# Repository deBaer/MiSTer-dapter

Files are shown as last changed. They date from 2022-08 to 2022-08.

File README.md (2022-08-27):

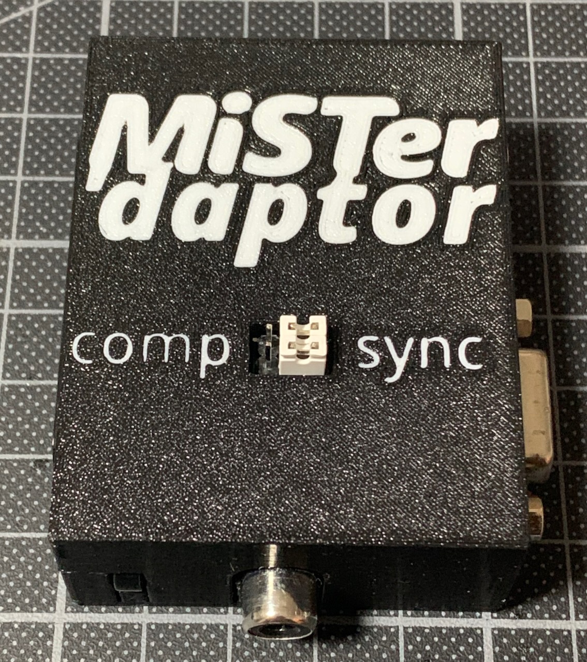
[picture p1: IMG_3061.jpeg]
MiSTer'daptor in case


# MiSTer'dapter
A VGA and audio jack to RGB SCART converter with RCA sync or composite output for the MiSTer FPGA

    Copyright (C) 2022 Simon Kowalewski

    This program is free software; you can redistribute it and/or modify
    it under the terms of the GNU General Public License as published by
    the Free Software Foundation; either version 2 of the License, or
    (at your option) any later version.

    This program is distributed in the hope that it will be useful,
    but WITHOUT ANY WARRANTY; without even the implied warranty of
    MERCHANTABILITY or FITNESS FOR A PARTICULAR PURPOSE.  See the
    GNU General Public License for more details.

    You should have received a copy of the GNU General Public License along
    with this program; if not, write to the Free Software Foundation, Inc.,
    51 Franklin Street, Fifth Floor, Boston, MA 02110-1301 USA.

## Video demonstration
[YouTube](https://youtu.be/DpnR34e562k) (Spoken languague is German, English subtitles are available)
	
## Build yourself
You'll need the [board](board) manufactured on 1.6 mm substrate. Also, you'll need a fitting SCART, VGA, RCA and mini phone jack. (I'll add links later.) You'll also need a 470 ohm resistor for attenuating the sync signal to SCART-safe levels and, optionally but recommended, a capacitor and inductance for the luma trap. I use 33 uH and 68 pF. If you don't use C1 and L1, bridge C1 with a resistor leg.

Optionally, 3D-print the [case](case). If you can multi-color print, print case.stl and print.stl together in different colors. If you cannot, don't print print.stl. If you want to use the case, populate the jumpers on the back side of the PCB (the side without silkscreen print).

## Buy from me
I don't have a web shop right now, so just send a mail to deBaer@gmail.com and tell me how many kits you want (15 €/kit), your preferred jumper color (black, white, blue, red, green and yellow available), if I should solder and test them for you (+10 €/kit), if you want cases (+10 €/case) and your post address (postage is 6€ flat for Germany for registered mail, I'll calculate the International postage on demand). I'll send you a confirmation with the expected delivery date, the final price and payment information, most likely Paypal. If you cannot or don't want to use Paypal, also indicate that in your email. Use a subject header containing "[daptor]" so I'll see the mail.

## Buy from someone else
If you offer to sell MiSTer'dapter kits, I'll list you here. Non-EU sellers are especially welcome, as I don't like customs forms. But please, attribute me and link back to this page.

## Usage
Connect the MiSTer'daptor to your MiSTer with a normal VGA cable.

Note: For the Guncon 2 or any other lightguns to work, the video has to go directly from the core to the CRT. No `vga_scaler`, no `scandoubler`! Also, no plasma, LCD, OLED! It may work with `direct_video` over the HDMI port, but that depends on both the device as well as the settings.

### RGB SCART
Connect the MiSTer'daptor to your TV with a RGB-capable SCART cable (not all are). For audio, connect the MiSTer'daptor with a normal TRS mini jack cable to the MiSTer. Optionally, connect Guncon 2 or other controllers that need sync to the RCA jack. Use these .ini settings:

```
forced_scandoubler=0
ypbpr=0 
composite_sync=1
vga_scaler=0
```

### Composite
Connect the MiSTer'daptor RCA plug to a composite input (normally yellow) on the TV. Connect the MiSTer audio out directly to the TV. You need to use [Y/C-capable cores](https://github.com/MikeS11/MiSTerFPGA_YC_Encoder) and switch to Y/C video mode in the core config dialog. Use these .ini settings:

```
forced_scandoubler=0
ypbpr=0 
composite_sync=1
vga_scaler=0
vga_sog=1
```

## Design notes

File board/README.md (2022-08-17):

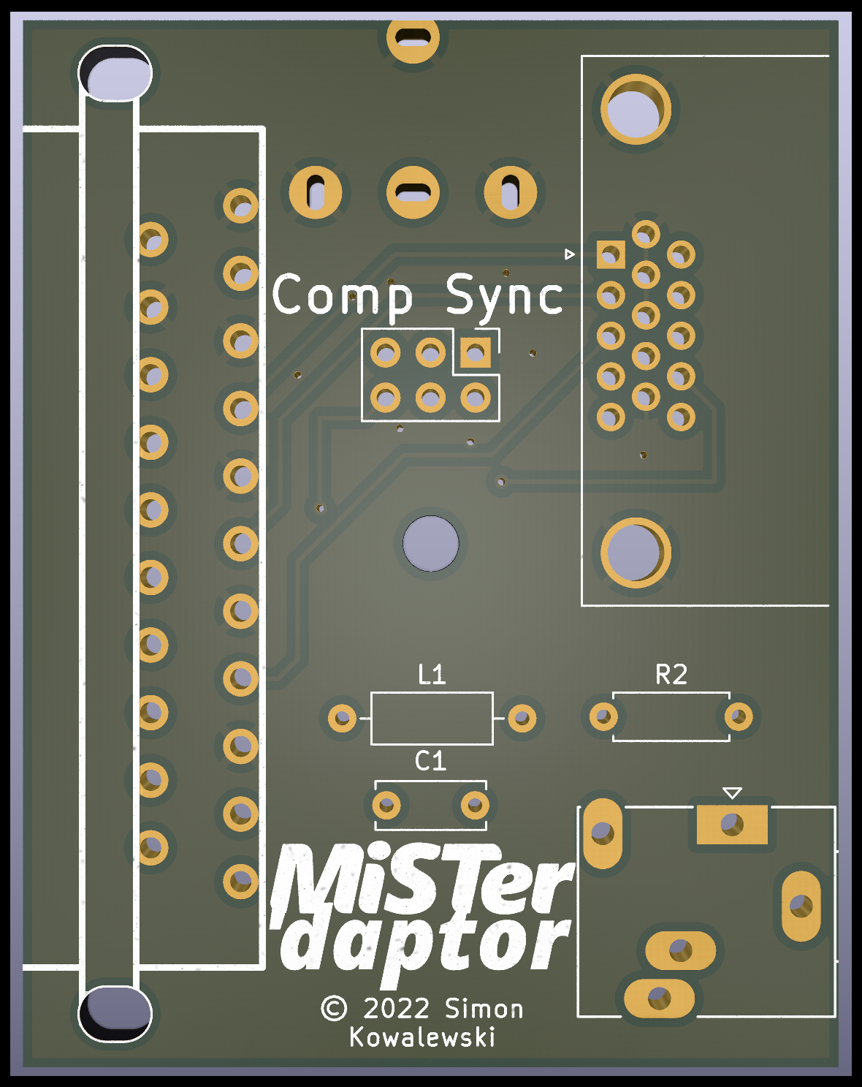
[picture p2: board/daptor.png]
MiSTer'daptor board


# MiSTer'dapter board
A VGA and audio jack to RGB SCART converter with RCA sync or composite output for the MiSTer FPGA

    Copyright (C) 2022 Simon Kowalewski

    This program is free software; you can redistribute it and/or modify
    it under the terms of the GNU General Public License as published by
    the Free Software Foundation; either version 2 of the License, or
    (at your option) any later version.

    This program is distributed in the hope that it will be useful,
    but WITHOUT ANY WARRANTY; without even the implied warranty of
    MERCHANTABILITY or FITNESS FOR A PARTICULAR PURPOSE.  See the
    GNU General Public License for more details.

    You should have received a copy of the GNU General Public License along
    with this program; if not, write to the Free Software Foundation, Inc.,
    51 Franklin Street, Fifth Floor, Boston, MA 02110-1301 USA.

This board was created in KiCAD 6. Source files as well as ready-for-production (I use JLCPCB) files are in this directory. For more information, see the [top directory](https://github.com/deBaer/MiSTer-dapter).

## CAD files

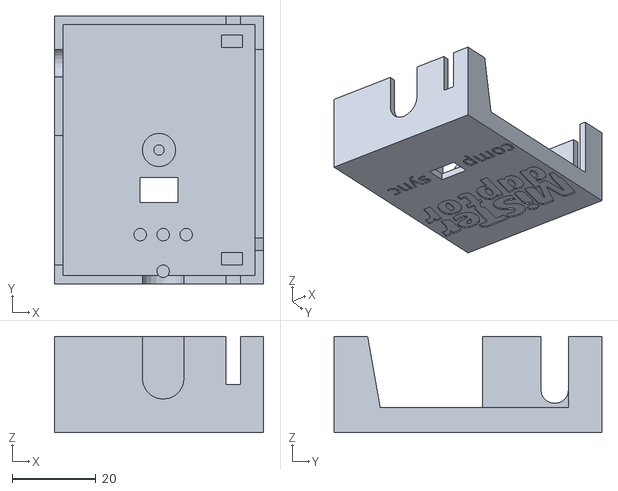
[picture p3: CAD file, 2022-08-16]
case/case.stl
50.0 x 64.0 x 23.0

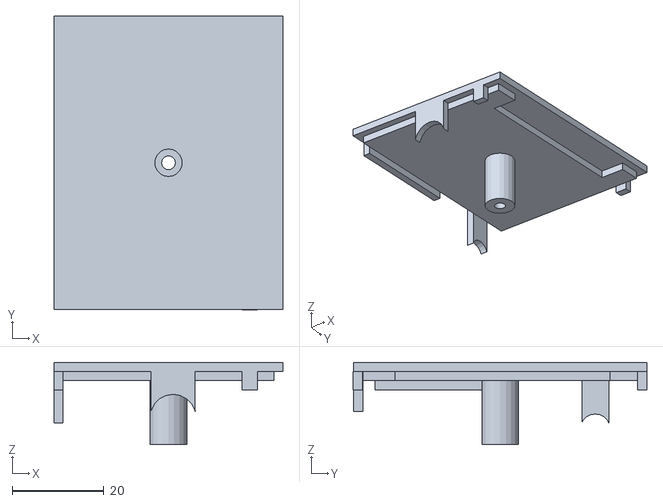
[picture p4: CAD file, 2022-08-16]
case/lid.stl
50.0 x 64.1 x 18.0

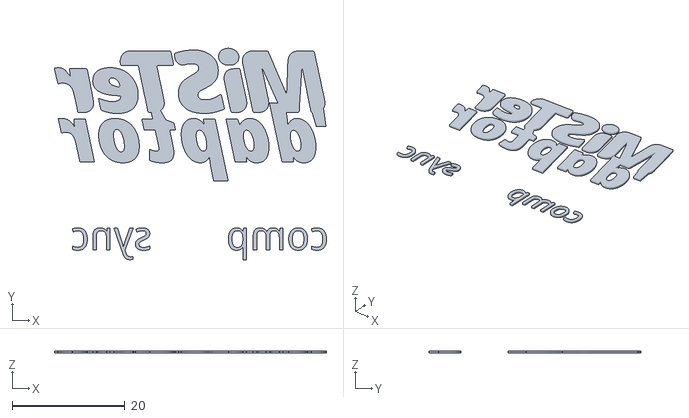
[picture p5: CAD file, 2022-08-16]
case/print.stl
48.2 x 37.5 x 0.4

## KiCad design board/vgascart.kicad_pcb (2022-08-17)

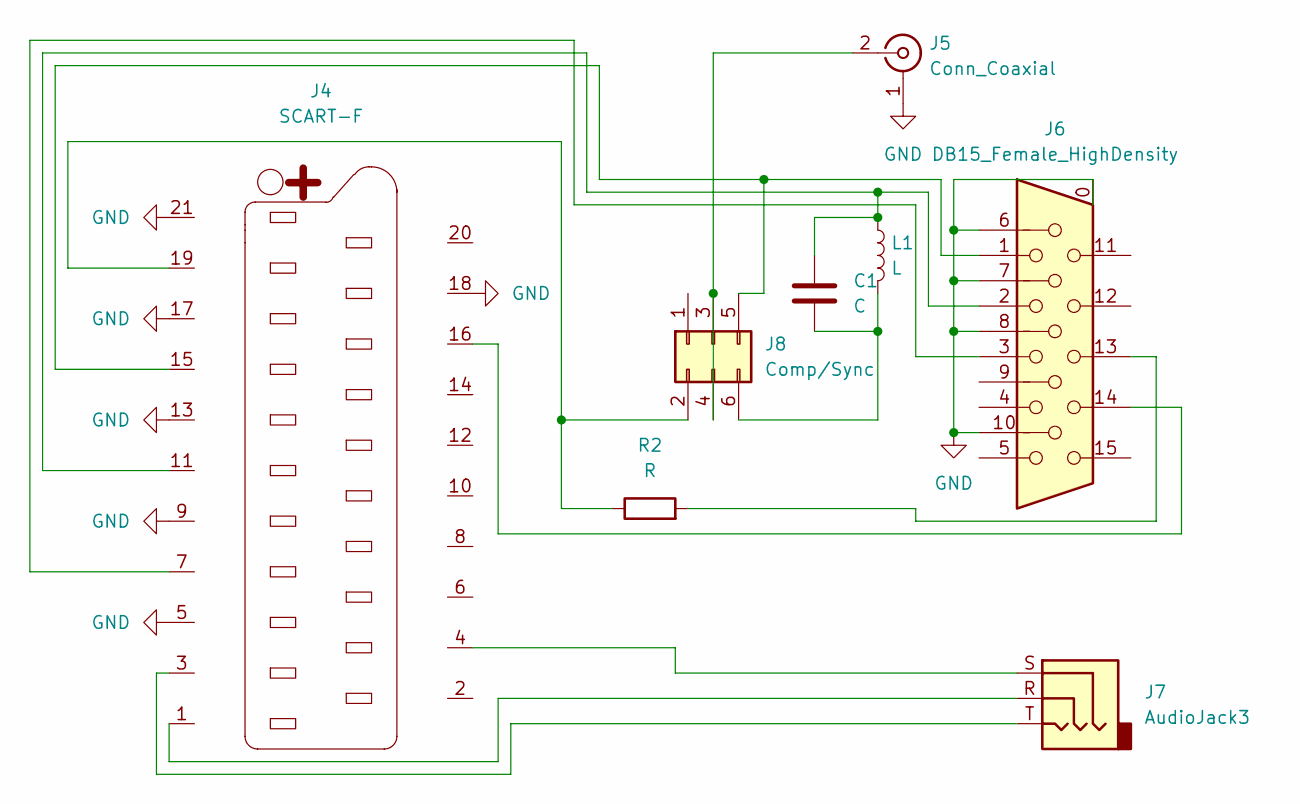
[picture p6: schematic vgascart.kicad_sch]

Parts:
C1: C; C_Disc_D6.0mm_W2.5mm_P5.00mm
J4: SCART-F; SCART.kicad_mod
J5: Conn_Coaxial; CBP C160
J6: DB15_Female_HighDensity; DSUB-15-HD_Female_Horizontal_P2.29x1.98mm_EdgePinOffset8.35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
J7: AudioJack3; Jack_3.5mm_Ledino_KB3SPRS_Horizontal
J8: Comp/Sync; PinHeader_2x03_P2.54mm_Vertical
L1: L; L_Axial_L6.6mm_D2.7mm_P10.16mm_Horizontal_Vishay_IM-2
R2: R; R_Axial_DIN0207_L6.3mm_D2.5mm_P7.62mm_Horizontal

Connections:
GND: J4.5, J4.9, J4.13, J4.17, J4.18, J4.21, J5.1 (Ext), J6.0, J6.6, J6.7, J6.8, J6.10
unnamed: C1.2, J8.6, L1.2
unnamed: J4.1, J7.R
unnamed: J4.3, J7.T
unnamed: J4.4, J7.S
unnamed: J4.7, J6.3
unnamed: C1.1, J4.11, J6.2, L1.1
unnamed: J4.15, J6.1, J8.5
unnamed: J4.16, J6.14
unnamed: J5.2 (In), J8.3, J8.4
unnamed: J6.13, R2.2
unnamed: J4.19, J8.2, R2.1

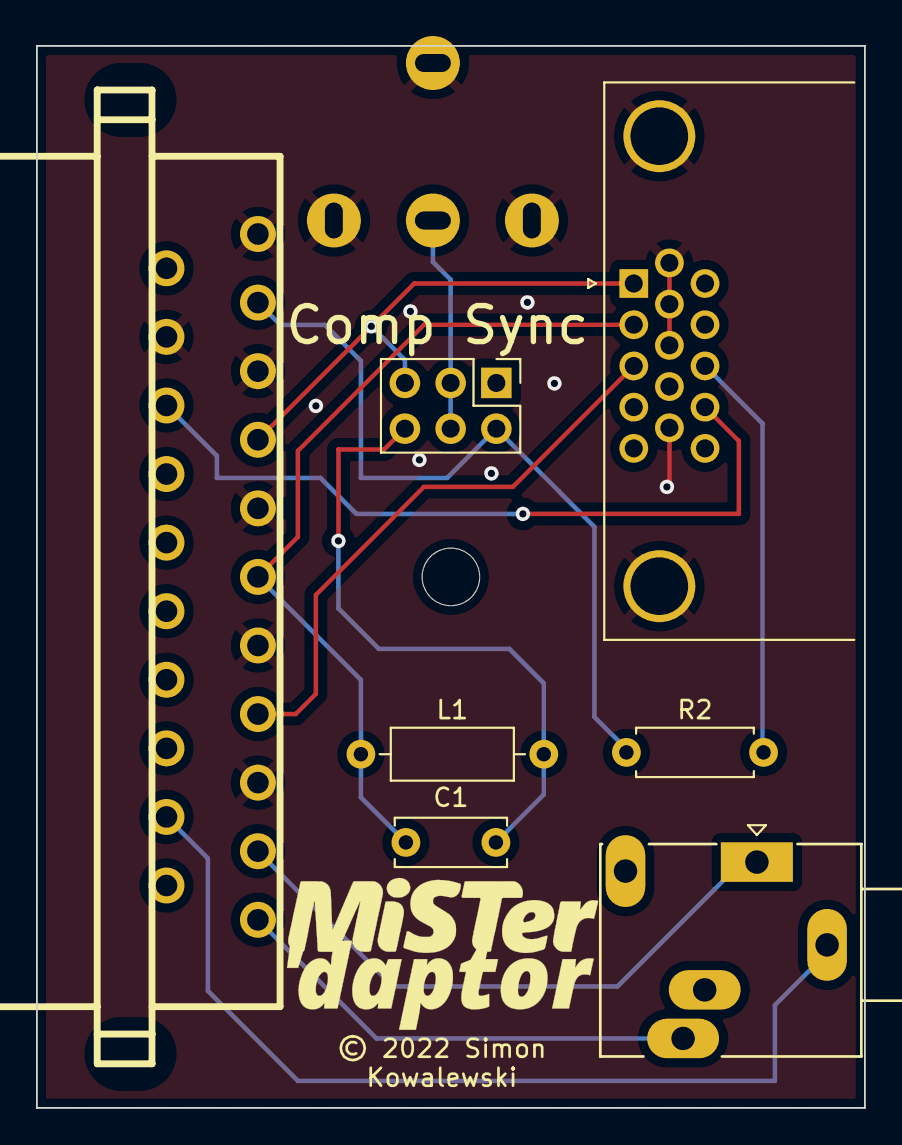
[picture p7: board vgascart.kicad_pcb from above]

Board: 2 copper layers, 46.0 x 59.0 mm, 8 parts (0 on the bottom side), 12 nets.

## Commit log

2022-08-16 Initial commit
    Initial commit
    [case.stl, lid.stl, print.stl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]
2022-08-17 Board cleanup, README
    [vgascart-B_Cu.gbl, vgascart-B_Mask.gbs, vgascart-B_Paste.gbp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]

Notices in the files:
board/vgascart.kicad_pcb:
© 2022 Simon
